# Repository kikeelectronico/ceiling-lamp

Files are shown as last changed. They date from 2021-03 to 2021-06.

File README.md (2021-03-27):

View this project on [CADLAB.io](https://cadlab.io/project/24088). 

# Celling lamp


An AC output controlled by an ESP8266 and powered by AC main

### Firmwares

#### Test

This firmware allows you to test the hardware if needed. It will change the relay status each 400 millisenconds when the button is pressed and it will send the push button status via serial communication.

#### AdafruitIO

This firmware is based in the Adafruit example for comumnicate with its MQTT broker called AdafruitIO. You can see more in <a href="https://io.adafruit.com">io.adafruit.com</a>

In order to use it you should set:

- Your WiFi setting
- You Adafruit user name
- API Key from Adafruit IO
- The MQTT feed which will be used in Adafruit IO

#### MQTT

This firmware allows you to communicate with a MQTT broker. For example, you can install your own MQTT broker in a Raspberry Pi.

This is the actual firmware that I am using at home with this circuit, and it is prepared for being working 24/7. It does:

- Recovery after a power failure.
- Wake up message
- Reconnect message
- Serial debug
- WiFi reconnect if the signal is lost
- MQTT Broker reconnect if the signal is lost

### For future revisions

- `Diode Footprint`: It is wrong in the PCB design
- `ESP8266`: ESP8266 as SoC instead of the ESP8266-12E module
- `UPS`: Uninterrupted Power System. Cesar Fernández idea
- `Capacitive button`: A capacitive external button that acts as the push button

***

<br /><span xmlns:dct="http://purl.org/dc/terms/" property="dct:title">Ceiling lamp</span> by <span xmlns:cc="http://creativecommons.org/ns#" property="cc:attributionName">Enrique Gómez</span> licensed by <a rel="license" href="http://creativecommons.org/licenses/by-sa/4.0/">Creative Commons Attribution-ShareAlike 4.0 International License</a>.<br /><br />

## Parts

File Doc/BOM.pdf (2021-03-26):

# Ceilling lamp – Bill of Materials

Rev.: 1 | Made By: Enrique Gómez | Verify By: | Date:
Item Designator | Description | Ordering code | Suplier | Manufacturer | Footprint Qty. | Ordering code 2 | Suplier 2 | Value
1 | U2 | ESP8266 | - | - | - | - | 1 | - | - | -
2 | U3 | Bloque AC/DC | HLK-PM01 | - | Hi-link | | 1 | HLK-PM01 | HLK-PM01 | 5V output
3 | Q1 | Transistor | 512-FDT86246L | Mouser | On Semiconductor | SOT-223-4 | 1 | FDT86246L | On Semiconductor
4 | D1 | Diodo | 512-RGF1B | Mouser | On Semiconductor | DO-214AC | 1 | RGF1B | On Semiconductor | Vf = 1000v; If = 1A
5 | K1 | Relé | 655-1461492-2 | Mouser | TE Connectivity | - | 1 | 1461492-2 | TE Connectivity
6 | SW1 | Pulsador | 611-PTS647SN70SMTR2L | Mouser | C&K | 4,5 x 4,5 mm | 1 | PTS647SN70SMTR2LFS C&K | SPST
7 | R1,R2,R3 | Resistencia | 279-CRGP0603F10K | Mouser | TE Connectivity | 0603 | 3 | CRGP0603F10K | TE Connectivity | 10k
8 | D2 | LED verde | 710-150060VS75000 | Mouser | Wurth Electronics | 0603 | 1 | 150060VS75000 | Wurth Electronics | Vf = 2v; If = 20 mA
9 | R4 | Resistencia | 754-RR0816Q-82R5D89R | Mouser | Susumu | 0603 | 1 | RR0816Q-82R5-D-89R | Susumu | 82,5 Ohm
10 | U1 | Regulador voltaje 755-BU33SD5WG-TR | Mouser | ROHM Semiconductor | SOT-23-5 | 1 | BU33SD5WG-TR | ROHM Semiconductor 3,3V
11 | C1, C2 | Condensador | 77-VJ0603G474KXQPBC | Mouser | Vishay | 0603 | 2 | VJ0603G474KXQPW1BC Vishay | 470nf
12 | J2 | Header pins | - | - | - | - | 1 | - | - | 01 x 06 pin
13 | J1,J3 | Screw Terminal | 651-1985920 | Mouser | Phoenix Contact | 2 x 5 mm | 2 | 1985920 | Phoenix Contact | I = 16A; V = 320v

### Notas:

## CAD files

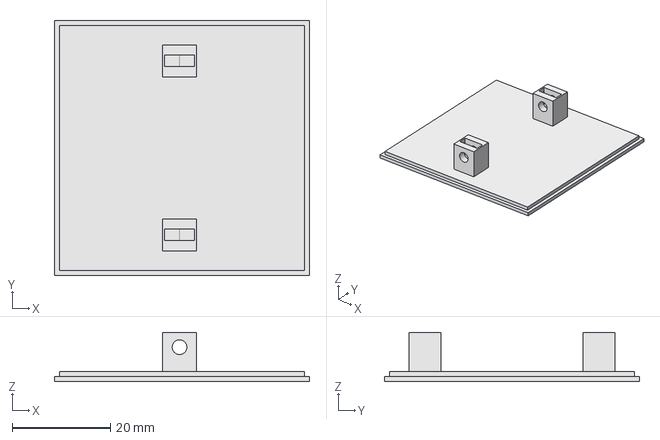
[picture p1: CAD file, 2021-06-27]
3D/Case/Cover.FCStd
52.0 x 52.0 x 10.0 mm

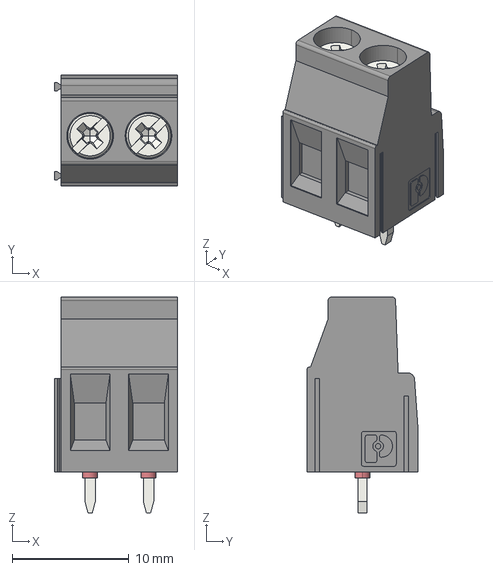
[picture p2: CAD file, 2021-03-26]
KiCad/Ceiling lamp/3dpackages/pxc_1985920_00_MKDSN-2-5-2-HT-BK_3D.stp
10.6 x 9.50 x 18.5 mm
Bohrloch x 2
mkdsn_2.5-2-ht_bk

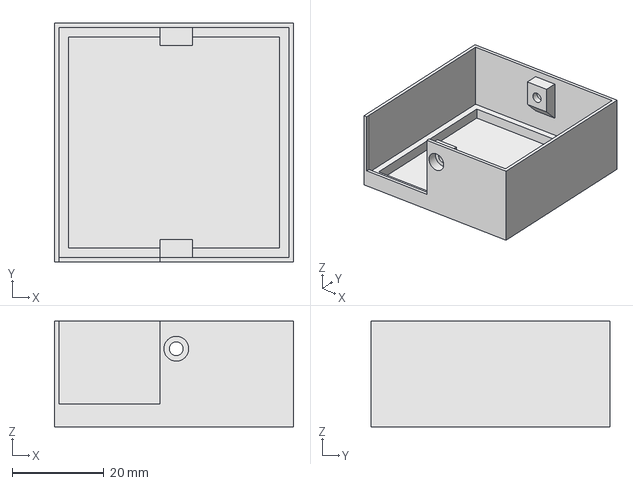
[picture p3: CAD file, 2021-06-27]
3D/Case/Base.FCStd
52.0 x 52.0 x 23.0 mm

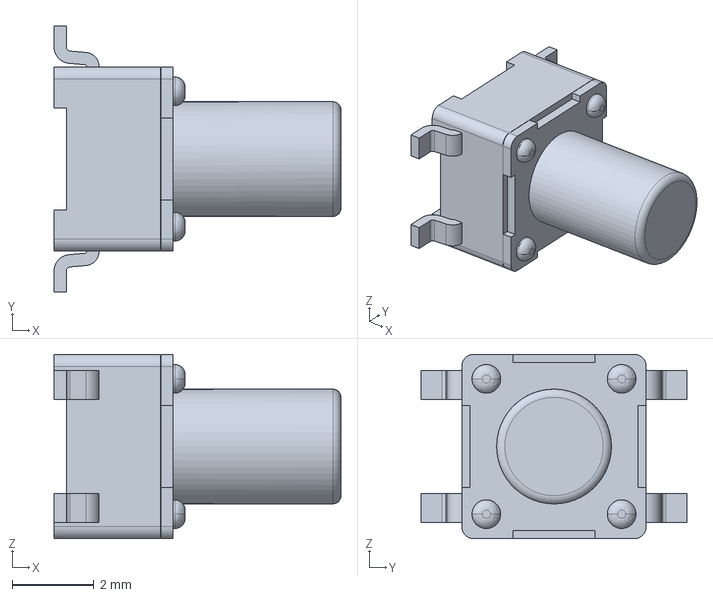
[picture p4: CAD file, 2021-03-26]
KiCad/Ceiling lamp/3dpackages/PTS647SN70SMTR2LFS.stp
7.00 x 6.50 x 4.50 mm

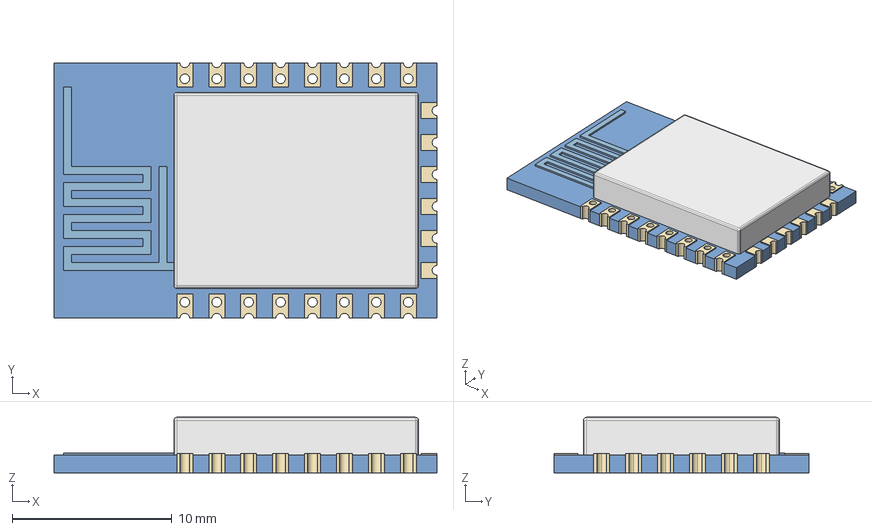
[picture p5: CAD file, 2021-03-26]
KiCad/Ceiling lamp/3dpackages/ESP8266.fcstd
24.0 x 16.0 x 3.48 mm

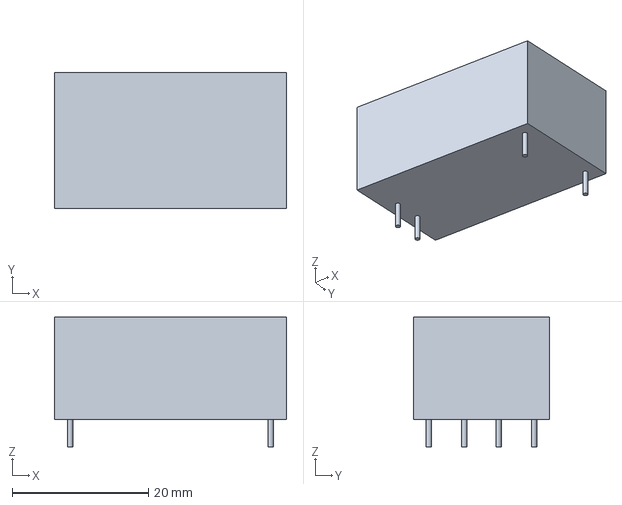
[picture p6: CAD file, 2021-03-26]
KiCad/Ceiling lamp/3dpackages/AC-DC_HLK-PM01.fcstd
34.0 x 20.0 x 19.0 mm

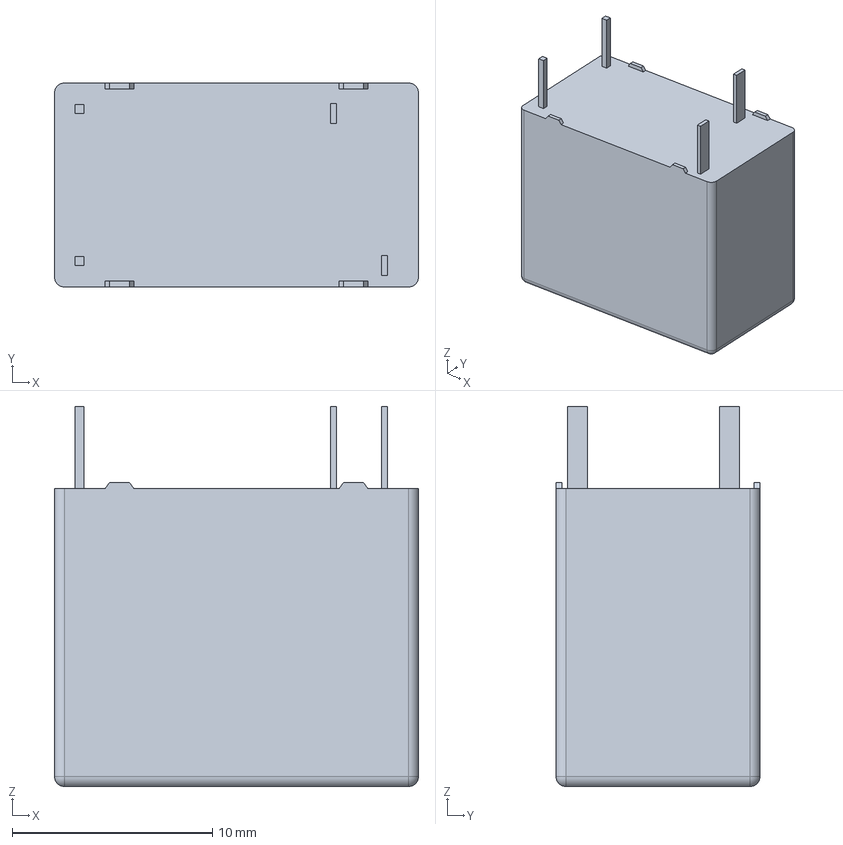
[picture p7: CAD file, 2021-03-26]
KiCad/Ceiling lamp/3dpackages/c-1461492-2-d4-3d.stp
18.2 x 10.2 x 19.0 mm

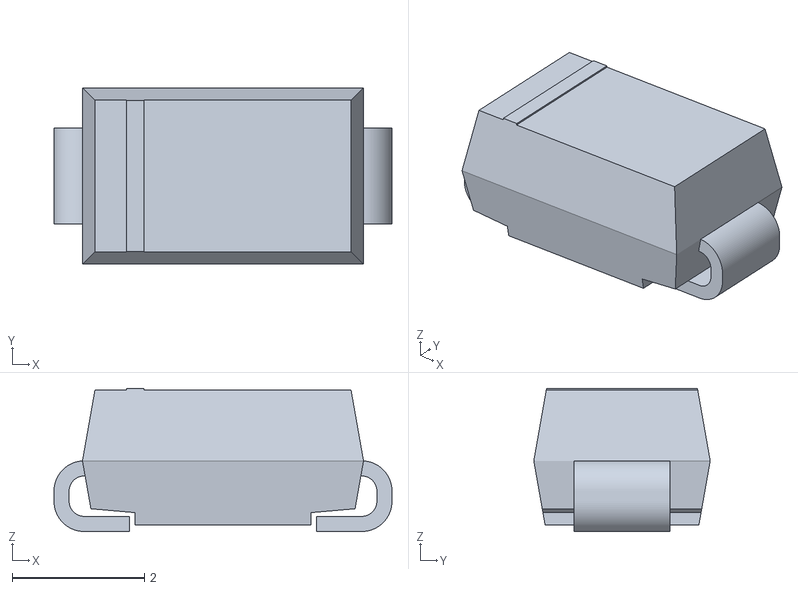
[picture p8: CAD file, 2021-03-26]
KiCad/Ceiling lamp/3dpackages/AB2_DO-214AC_WINGS3D.stl
5.11 x 2.66 x 2.16

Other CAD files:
KiCad/Ceiling lamp/3dpackages/ESP8266-12E.stp
3D/Case/Base.stl
3D/Case/Cover.stl

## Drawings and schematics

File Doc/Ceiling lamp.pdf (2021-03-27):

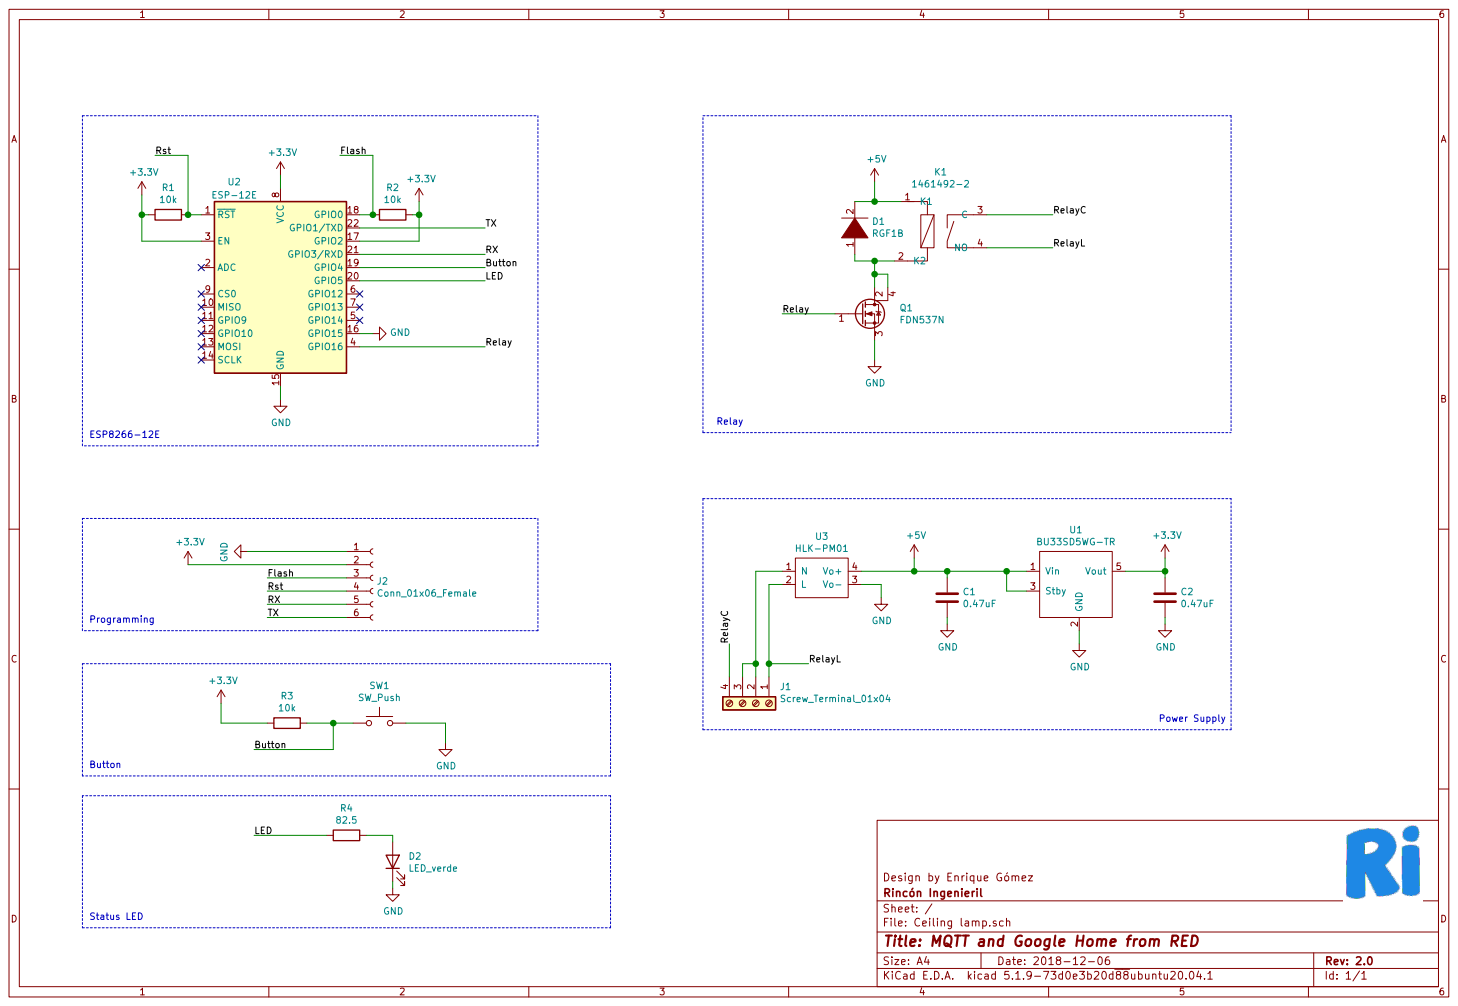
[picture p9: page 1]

Design by Enrique Gómez GND

File: Ceiling lamp.sch Sheet: / Rincón Ingenieril

Id: 1/1 Title: MQTT and Google Home from RED

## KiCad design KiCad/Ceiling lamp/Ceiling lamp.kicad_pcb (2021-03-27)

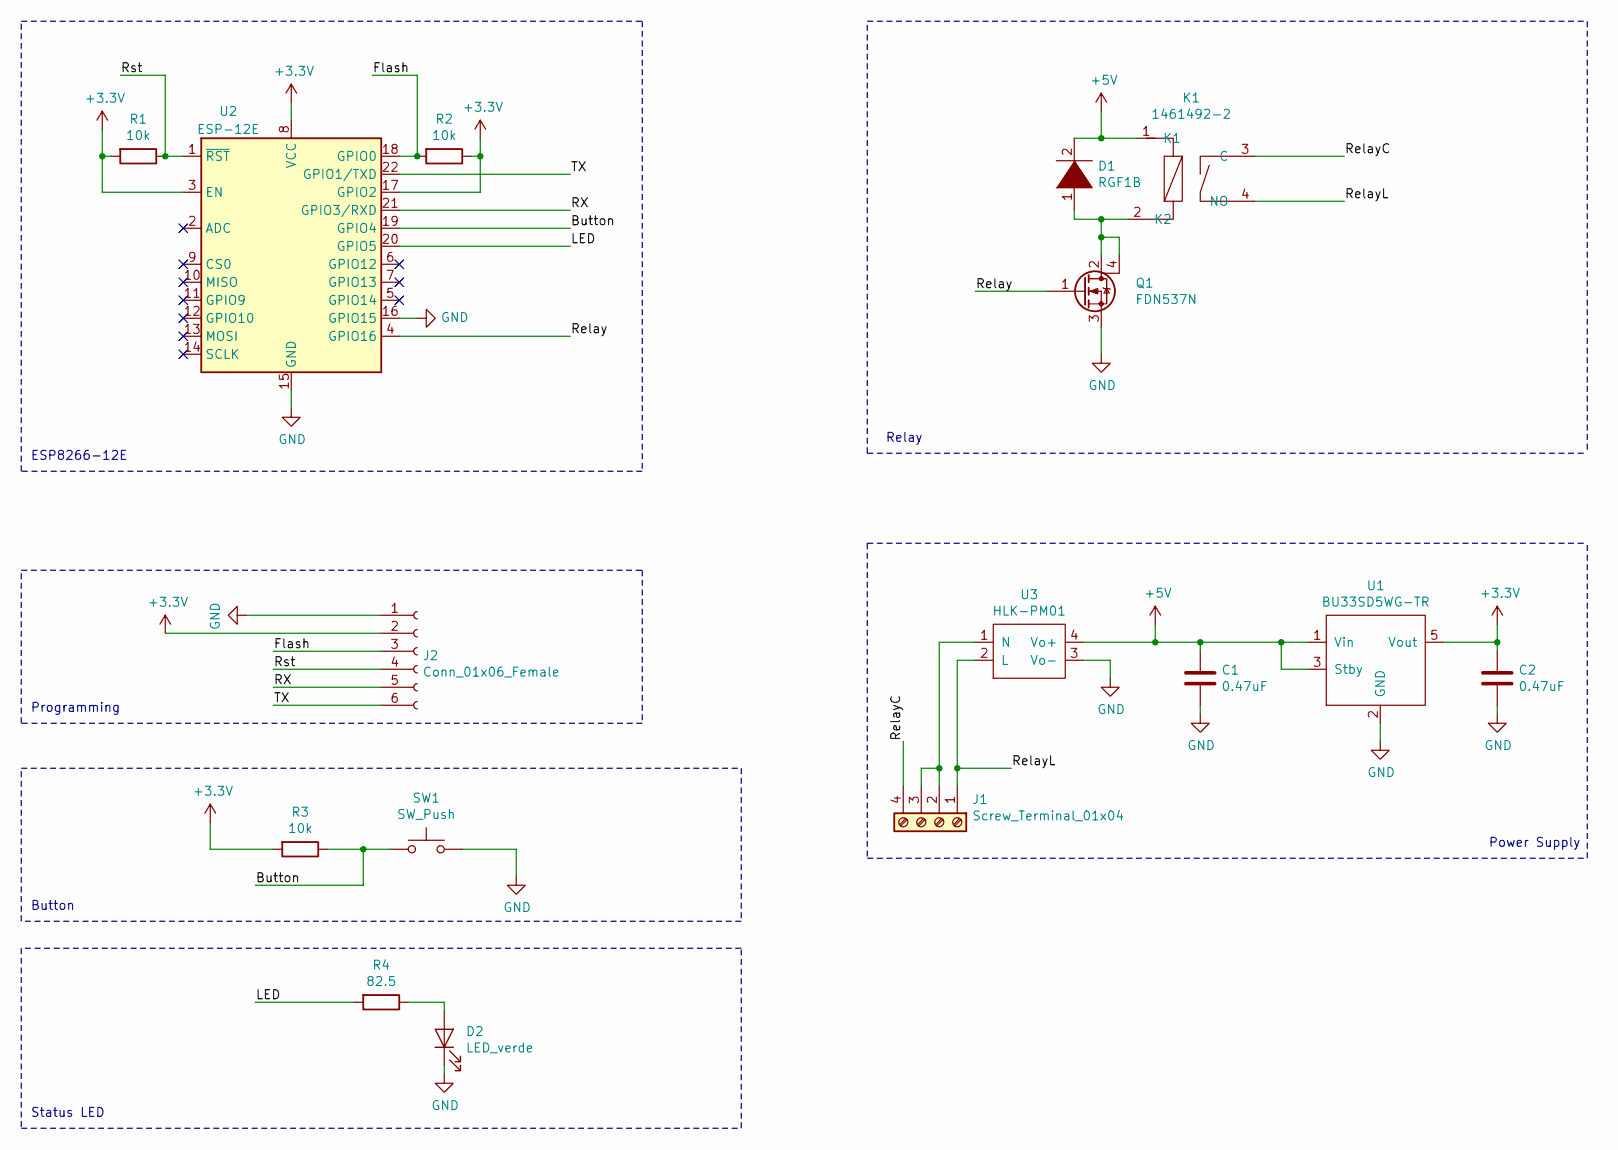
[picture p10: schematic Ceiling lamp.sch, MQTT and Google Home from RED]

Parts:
C1, C2: 0.47uF; C_0603_1608Metric
D1: RGF1B; D_0201_0603Metric
D2: LED_verde; LED_0603_1608Metric
J1: Screw_Terminal_01x04; TerminalBlock_Phoenix_MKDS-1,5-4_1x04_P5.00mm_Horizontal
J2: Conn_01x06_Female; PinHeader_1x06_P2.54mm_Vertical
K1: 1461492-2; Rele-1461492-2
Q1: FDN537N; SOT-223
R1, R2, R3: 10k; R_0603_1608Metric_Pad1.05x0.95mm_HandSolder
R4: 82.5; R_0603_1608Metric_Pad1.05x0.95mm_HandSolder
SW1: SW_Push; SW_SPST_EVQP2
U1: BU33SD5WG-TR; TSOP-5_1.65x3.05mm_P0.95mm
U2: ESP-12E
U3: HLK-PM01

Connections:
+3V3: C2.1, J2.2, R1.2, R2.1, R3.2, U1.5 (Vout), U2.3 (EN), U2.8 (VCC), U2.17 (GPIO2)
+5V: C1.1, D1.2 (A), K1.1 (K1), U1.1 (Vin), U1.3 (Stby), U3.4 (Vo+)
/Button: R3.1, SW1.1, U2.19 (GPIO4)
/Flash: J2.3, R2.2, U2.18 (GPIO0)
/LED: R4.2, U2.20 (GPIO5)
/RX: J2.5, U2.21 (GPIO3/RXD)
/Relay: Q1.1 (G), U2.4 (GPIO16)
/RelayC: J1.4, K1.3 (C)
/RelayL: J1.1, K1.4 (NO), U3.2 (L)
/Rst: J2.4, R1.1, U2.1 (~RST)
/TX: J2.6, U2.22 (GPIO1/TXD)
GND: C1.2, C2.2, D2.1 (K), J2.1, Q1.3 (S), SW1.2, U1.2 (GND), U2.15 (GND), U2.16 (GPIO15), U3.3 (Vo-)
unnamed: D1.1 (K), K1.2 (K2), Q1.2 (D), Q1.4 (D)
unnamed: D2.2 (A), R4.1
unnamed: J1.2, J1.3, U3.1 (N)

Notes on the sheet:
Power Supply
ESP8266-12E
Programming
Relay
Button
Status LED

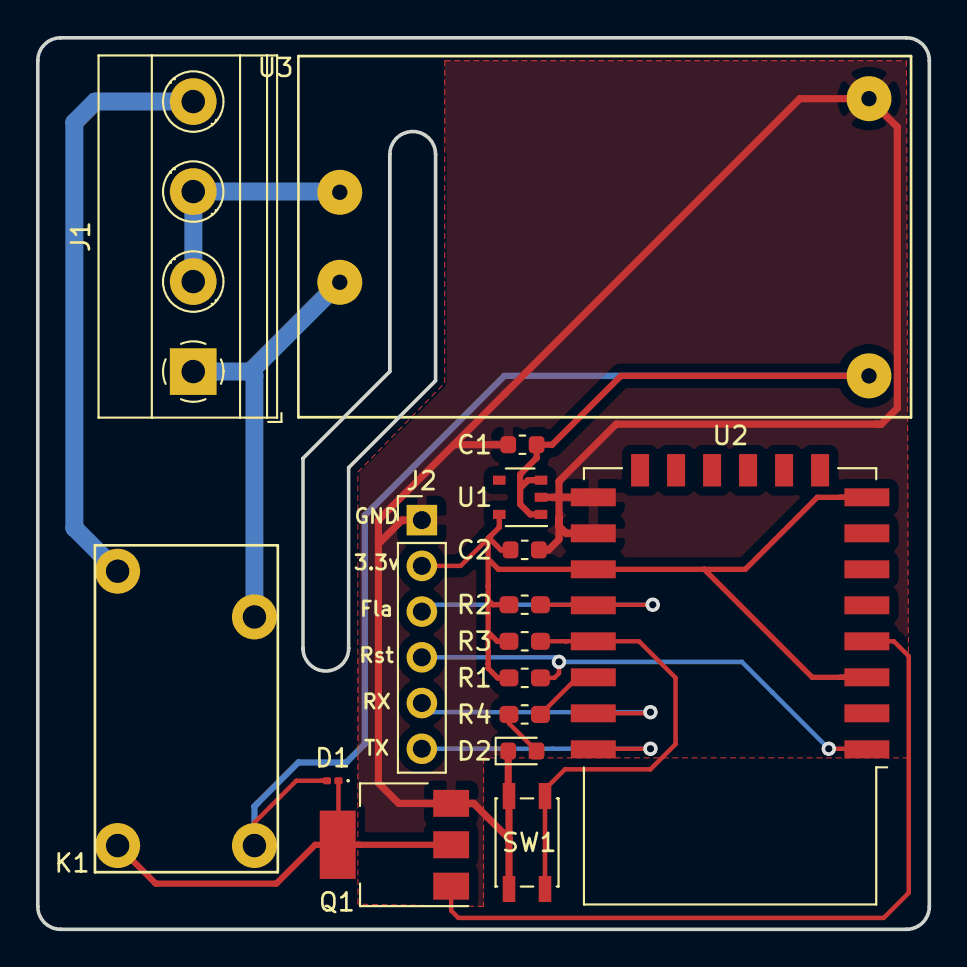
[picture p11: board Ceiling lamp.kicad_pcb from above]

Board: 2 copper layers, 49.5 x 49.5 mm, 16 parts (0 on the bottom side), 15 nets.

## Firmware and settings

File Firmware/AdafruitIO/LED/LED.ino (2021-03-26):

/***************************************************
  Adafruit MQTT Library ESP8266 Example

  Must use ESP8266 Arduino from:
    https://github.com/esp8266/Arduino

  Works great with Adafruit's Huzzah ESP board & Feather
  ----> https://www.adafruit.com/product/2471
  ----> https://www.adafruit.com/products/2821

  Adafruit invests time and resources providing this open source code,
  please support Adafruit and open-source hardware by purchasing
  products from Adafruit!

  Written by Tony DiCola for Adafruit Industries.
  MIT license, all text above must be included in any redistribution
 ****************************************************/
 /***************************************************
  Edited by Enrique Gómez as example for
  https://github.com/RinconIngenieril/Home-Automation-Devices

  Funcionamiento:
  - Al enviar ON al feed LED de Adafruit IO se apagará el LED
  - Al enviar OFF al feed LED de Adafruit IO se encenderá el LED
 ****************************************************/
#include <ESP8266WiFi.h>
#include "Adafruit_MQTT.h"
#include "Adafruit_MQTT_Client.h"

/************************* WiFi Access Point *********************************/

#define WLAN_SSID       "SSID"
#define WLAN_PASS       "PASSWORD"

/************************* Adafruit.io Setup *********************************/

#define AIO_SERVER      "io.adafruit.com"
#define AIO_SERVERPORT  1883                   // use 8883 for SSL
#define AIO_USERNAME    "nombreDeUsuarioAdafruitIO"
#define AIO_KEY         "tuApiKey"

/************ Global State (you don't need to change this!) ******************/

// Create an ESP8266 WiFiClient class to connect to the MQTT server.
WiFiClient client;

// Setup the MQTT client class by passing in the WiFi client and MQTT server and login details.
Adafruit_MQTT_Client mqtt(&client, AIO_SERVER, AIO_SERVERPORT, AIO_USERNAME, AIO_KEY);

/****************************** Feeds ***************************************/

// Setup a feed called 'onoff' for subscribing to changes.
Adafruit_MQTT_Subscribe onoffrelay = Adafruit_MQTT_Subscribe(&mqtt, AIO_USERNAME "/feeds/LED");

/*************************** Sketch Code ************************************/

void MQTT_connect();

void setup() {
  Serial.begin(115200);
  delay(10);

  pinMode(D0, OUTPUT);
  digitalWrite(D0, LOW);
  pinMode(D4, INPUT);


  /***************** Boot info **************************/
  Serial.println(F("Adafruit MQTT demo"));
  // Connect to WiFi access point.
  Serial.println(); Serial.println();
  Serial.print("Connecting to ");
  Serial.println(WLAN_SSID);
  WiFi.begin(WLAN_SSID, WLAN_PASS);
  while (WiFi.status() != WL_CONNECTED) {
    delay(500);
    Serial.print(".");
  }
  Serial.println();
  Serial.println("WiFi connected");
  Serial.println("IP address: "); Serial.println(WiFi.localIP());



  // Setup MQTT subscription for onoff feed.
  mqtt.subscribe(&onoffrelay);
}

void loop() {
  MQTT_connect();

  if (digitalRead(D2) == LOW){
      digitalWrite(D0, !digitalRead(D0));
      delay(200);
      Serial.println("Pulsado");
    }

  Adafruit_MQTT_Subscribe *subscription;
  while ((subscription = mqtt.readSubscription(1000))) {
    if (subscription == &onoffrelay) {
      Serial.print(F("Got: "));
      Serial.println(((char *)onoffrelay.lastread));

      if (strcmp((char *)onoffrelay.lastread, "ON") == 0){
        digitalWrite(D0, HIGH);
      } else {
        digitalWrite(D0, LOW);
      }
    }
  }


}

// Function to connect and reconnect as necessary to the MQTT server.
void MQTT_connect() {
  int8_t ret;

  // Stop if already connected.
  if (mqtt.connected()) {
    return;
  }

  Serial.print("Connecting to MQTT... ");

  uint8_t retries = 3;
  while ((ret = mqtt.connect()) != 0) { // connect will return 0 for connected
       Serial.println(mqtt.connectErrorString(ret));
       Serial.println("Retrying MQTT connection in 5 seconds...");
       mqtt.disconnect();
       delay(5000);  // wait 5 seconds
       retries--;
       if (retries == 0) {
         // basically die and wait for WDT to reset me
         while (1);
       }
  }
  Serial.println("MQTT Connected!");
}

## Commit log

2021-03-26 kick off
    [AB2_DO-214AC_WINGS3D.stl, AC-DC_HLK-PM01.fcstd, BOM.ods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]
2021-03-27 pcb changes v3
    [Ceiling lamp.kicad_pcb]
2021-06-27 3D case
    [Base.FCStd, Base.stl, Cover.FCStd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]
2021-06-27 3D case cover
    [Cover.FCStd, Cover.stl]

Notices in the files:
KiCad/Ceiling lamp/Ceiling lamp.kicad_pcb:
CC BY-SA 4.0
